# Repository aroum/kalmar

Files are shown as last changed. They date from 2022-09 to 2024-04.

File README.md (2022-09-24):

# Kalmar

My [Architeuthis dux](https://github.com/tapioki/cephalopoda/tree/main/Architeuthis%20dux) keyboard modification.

## Differences:
* Power switch
* Reset button
* Solder jumper for ProMicro(no need to flip the controller)
* Low profile case with magnets
* Additional mounting holes for case
  
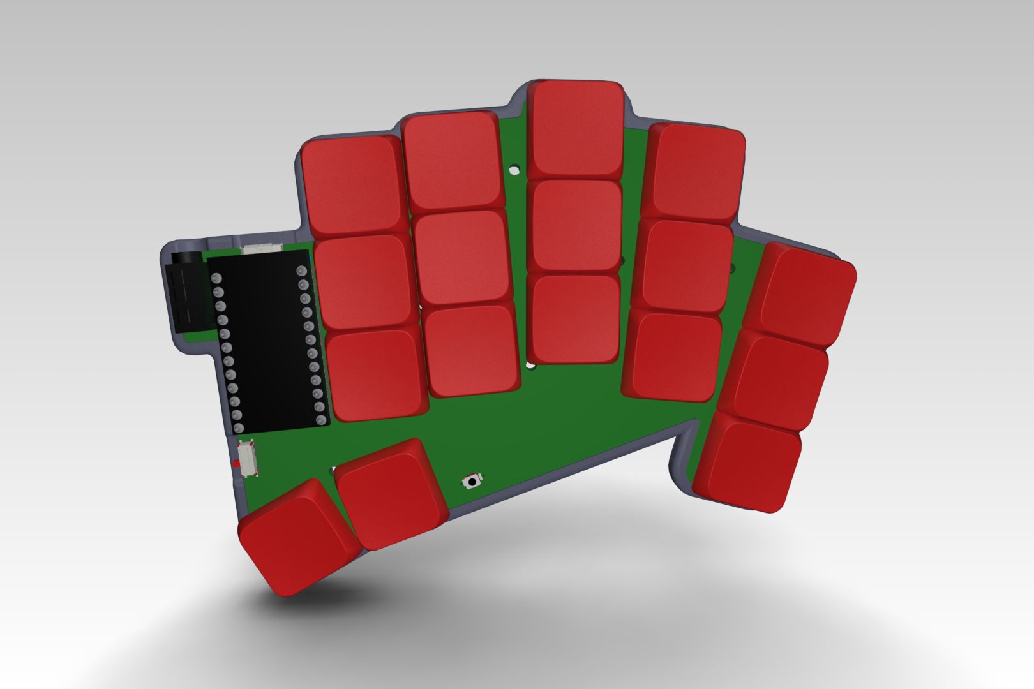
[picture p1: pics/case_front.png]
case_front

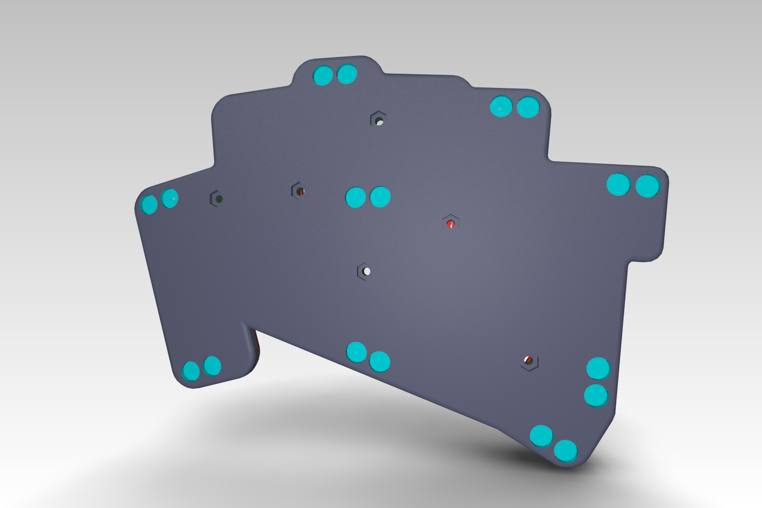
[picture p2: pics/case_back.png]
case_back

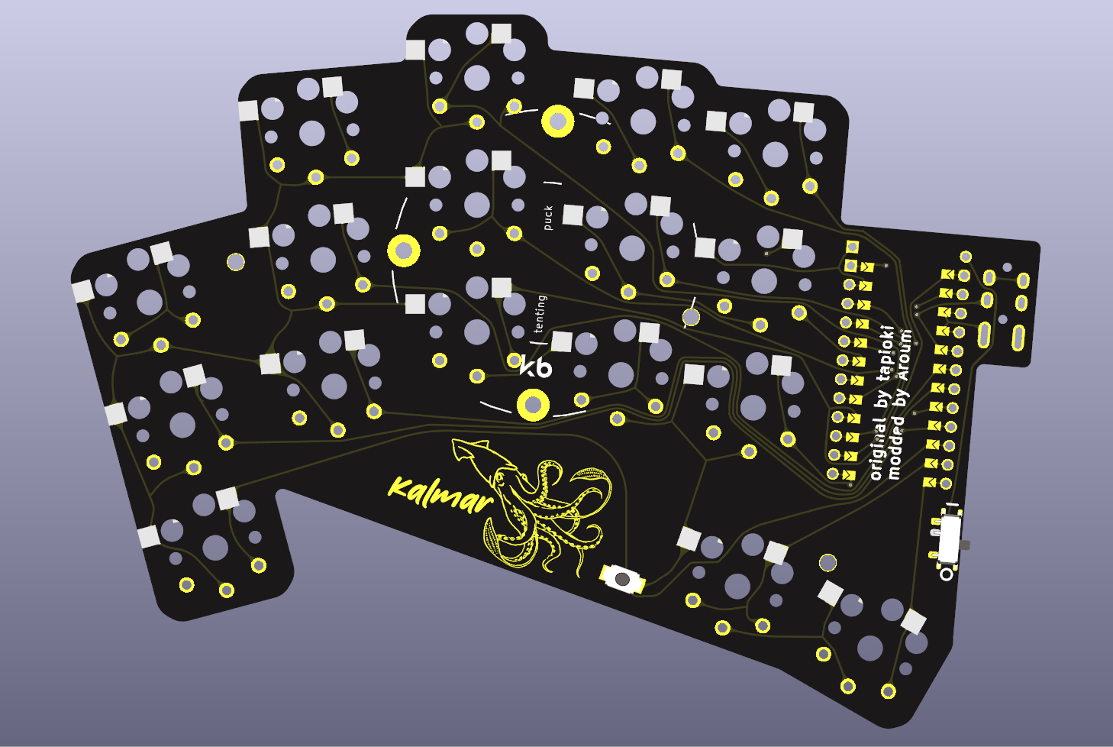
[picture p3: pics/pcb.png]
pcb


# BOM for keyboard

| Item | Quantity | Remarks |
| --- | ---: | --- |
| [proMicro](https://aliexpress.ru/item/32840365436.html) | 2 | or any other compatible controller |
| [Kailh Choc V1](https://aliexpress.ru/item/32959996455.html) | 34 | switches |
| [Keycaps](https://aliexpress.ru/item/33026798318.html) | 34 | 1U |
| [Magnets](https://aliexpress.ru/item/1005002757445161.html) | 2-6 | disc 7x2 mm (for case) |
| [Bumpers](https://aliexpress.ru/item/4001188580018.html) | 18 | 5x2 mm (for case) |
| [Sockets PH3.5](https://aliexpress.ru/item/32899635835.html) | 12x2 | for controller |
| [SMD button 3x4x2mm](https://aliexpress.ru/item/1005003812819985.html) | 2 | for reset |
| [MSK-12C02](https://aliexpress.ru/item/1005001398386692.html) | 2 | Power switch  (wireless only) |
| [301230](https://aliexpress.ru/item/32732458079.html) | 2 | Battery  (wireless only) |

Interactive BOM is located ```/pcb/ibom/ibom.html```

# GERBER

GERBER can be downloaded in [releases](https://github.com/aroum/kalmar/releases).

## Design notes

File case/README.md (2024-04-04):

# CASE

For right-handed version you need to mirror the model.

The pcb is fixed by friction or double-sided tape.

# BOM
* magnets size: 7x2mm (2-6 pcs)
* bumpons size: 5x2mm (7 pcs)

# Print options:
* Printer: Voxelab proxima
* Rafts: No
* Supports: Yes
* Resolution: 0.05mm
* Resin material: ABS-like

STL models can be downloaded in [releases](https://github.com/aroum/kalmar/releases).

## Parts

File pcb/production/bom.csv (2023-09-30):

Designator | Footprint | Quantity | Value | LCSC Part #
H1, H2, H3, H5 | HOLE | 4 | Hole
J1 | MJ-4PP-9_dual | 1 | MJ-4PP-9
RSW1 | SW_3x4x2_2legs_x2 | 1 | SW_PUSH
SW1 | switch_MSK-12C02_smd_x2 | 1 | SW_SPDT
SWr1c1, SWr1c2, SWr1c3, SWr1c4, SWr1c5, SWr2c1, SWr2c2, SWr2c3, SWr2c4, SWr2c5, SWr3c1, SWr3c2, SWr3c3, SWr3c4, SWr3c5, SWr4c1, SWr4c2 | ChocV1_duplex_hotswap_topor | 17 | SW_PUSH
U | ProMicro_duplex_clean | 1 | ProMicro_r

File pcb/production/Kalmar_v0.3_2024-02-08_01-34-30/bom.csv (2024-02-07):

Designator | Footprint | Quantity | Value | LCSC Part #
_2, |  | 2
H1, H2, H3, H5 | HOLE | 4 | Hole
J1 | MJ-4PP-9_dual_topor | 1 | MJ-4PP-9
RSW1 | SW_3x4x2_2legs_x2 | 1 | SW_PUSH
SW1 | switch_MSK-12C02_smd_x2_topor | 1 | SW_SPDT
SWr1c1, SWr1c2, SWr1c3, SWr1c4, SWr1c5, SWr2c1, SWr2c2, SWr2c3, SWr2c4, SWr2c5, SWr3c1, SWr3c2, SWr3c3, SWr3c4, SWr3c5, SWr4c1, SWr4c2 | ChocV1_duplex_hotswap_topor | 17 | SW_PUSH
U1 | ProMicro_duplex_clean | 1 | ProMicro_r

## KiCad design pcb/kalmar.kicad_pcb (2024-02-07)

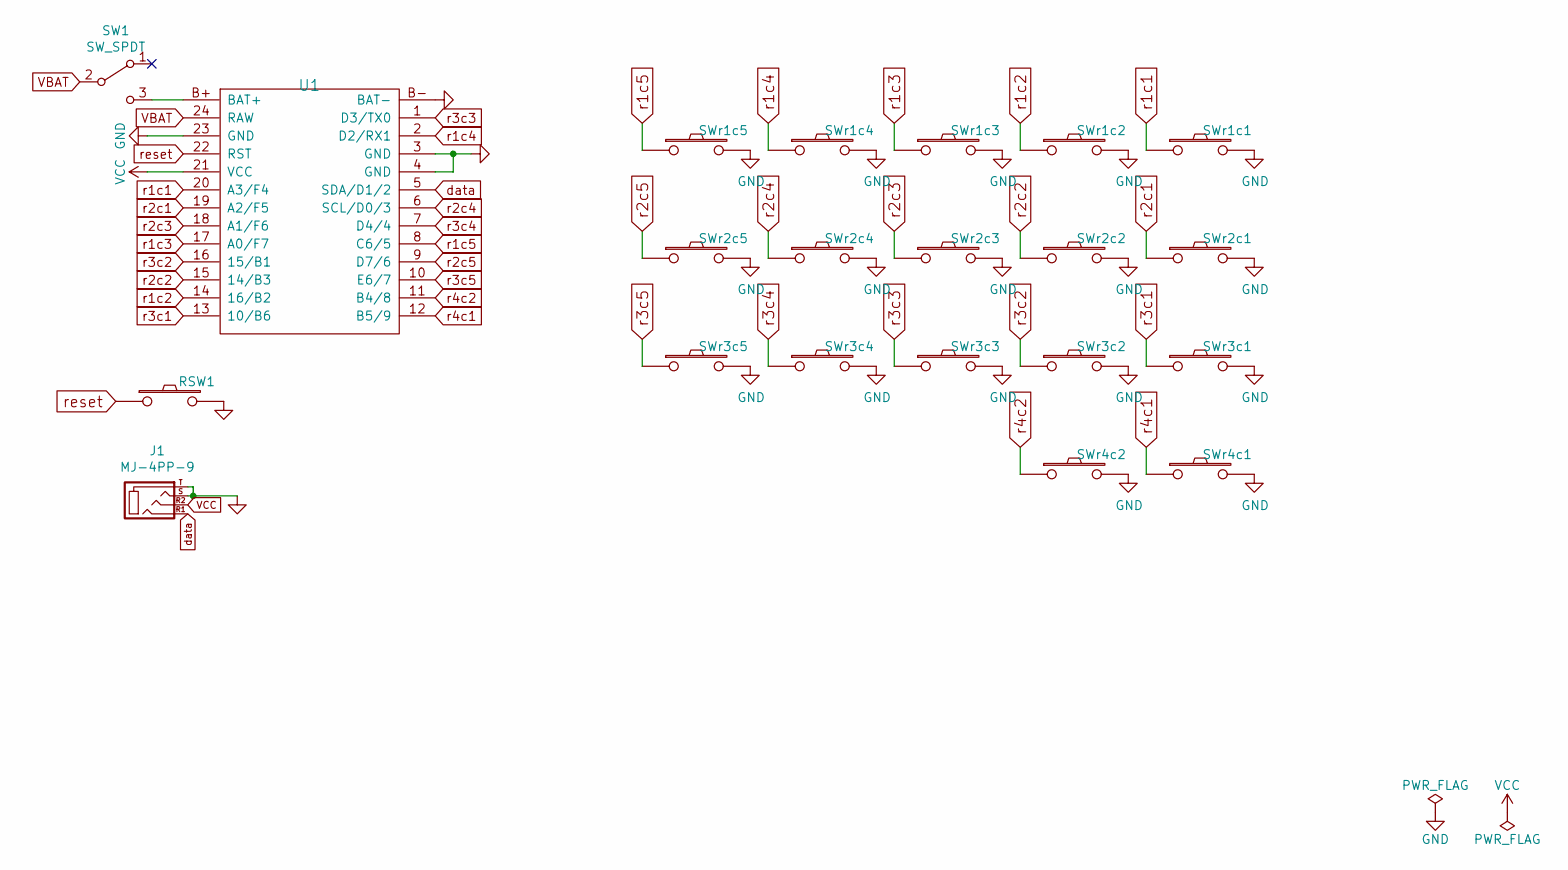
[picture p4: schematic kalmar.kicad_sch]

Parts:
J1: MJ-4PP-9; MJ-4PP-9_dual
RSW1: SW_PUSH; SW_3x4x2_2legs_x2
SW1: SW_SPDT; switch_MSK-12C02_smd_x2
SWr1c1, SWr1c2, SWr1c3, SWr1c4, SWr1c5, SWr2c1, SWr2c2, SWr2c3, SWr2c4, SWr2c5, SWr3c1, SWr3c2, SWr3c3, SWr3c4, SWr3c5, SWr4c1, SWr4c2: SW_PUSH; ChocV1_duplex_hotswap
U1: ProMicro_r; ProMicro_duplex_clean

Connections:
GND: J1.S, J1.T, RSW1.2, SWr1c1.2, SWr1c2.2, SWr1c3.2, SWr1c4.2, SWr1c5.2, SWr2c1.2, SWr2c2.2, SWr2c3.2, SWr2c4.2, SWr2c5.2, SWr3c1.2, SWr3c2.2, SWr3c3.2, SWr3c4.2, SWr3c5.2, SWr4c1.2, SWr4c2.2, U1.3 (GND), U1.4 (GND), U1.23 (GND), U1.B- (BAT-)
unnamed: SW1.3 (C), U1.B+ (BAT+)
VBAT: SW1.2 (B), U1.24 (RAW)
VCC: J1.R2, U1.21 (VCC)
data: J1.R1, U1.5 (SDA/D1/2)
r1c1: SWr1c1.1, U1.20 (A3/F4)
r1c2: SWr1c2.1, U1.14 (16/B2)
r1c3: SWr1c3.1, U1.17 (A0/F7)
r1c4: SWr1c4.1, U1.2 (D2/RX1)
r1c5: SWr1c5.1, U1.8 (C6/5)
r2c1: SWr2c1.1, U1.19 (A2/F5)
r2c2: SWr2c2.1, U1.15 (14/B3)
r2c3: SWr2c3.1, U1.18 (A1/F6)
r2c4: SWr2c4.1, U1.6 (SCL/D0/3)
r2c5: SWr2c5.1, U1.9 (D7/6)
r3c1: SWr3c1.1, U1.13 (10/B6)
r3c2: SWr3c2.1, U1.16 (15/B1)
r3c3: SWr3c3.1, U1.1 (D3/TX0)
r3c4: SWr3c4.1, U1.7 (D4/4)
r3c5: SWr3c5.1, U1.10 (E6/7)
r4c1: SWr4c1.1, U1.12 (B5/9)
r4c2: SWr4c2.1, U1.11 (B4/8)
reset: RSW1.1, U1.22 (RST)

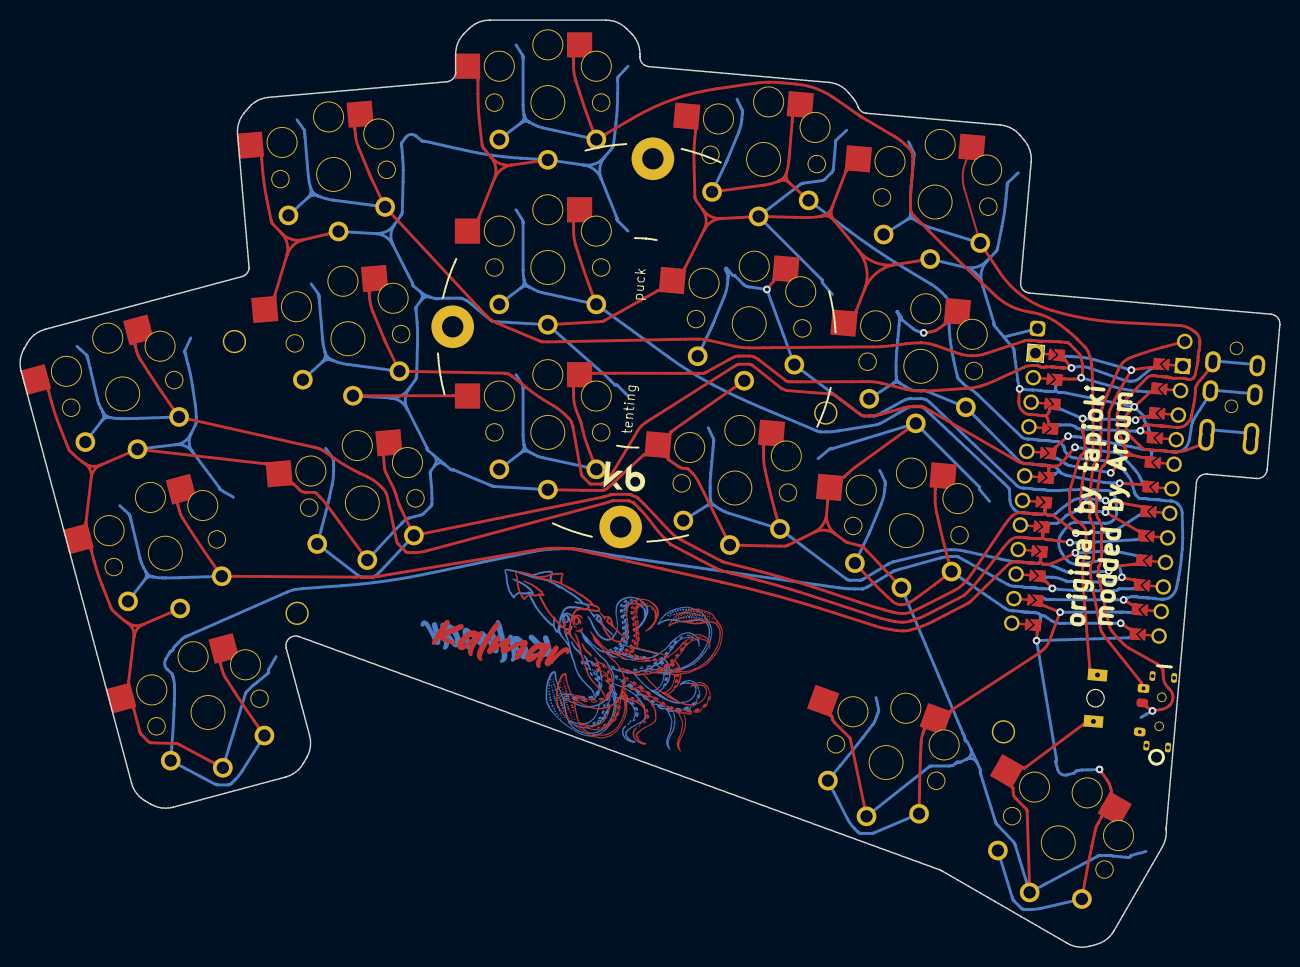
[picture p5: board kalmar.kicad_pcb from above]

Board: 2 copper layers, 129.9 x 95.6 mm, 25 parts (1 on the bottom side), 23 nets.

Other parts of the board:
H1, H2, H3, H5: Hole; HOLE

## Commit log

2023-09-30 some fixes
    [bom.csv, designators.csv, kalmar.kicad_sch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]
2024-02-07 v0.3
    fix connection
    add jack cut
    [bom.csv, designators.csv, kalmar.kicad_pcb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]
